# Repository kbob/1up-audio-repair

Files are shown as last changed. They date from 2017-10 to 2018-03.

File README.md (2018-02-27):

# Repair a 1UP's headphone jack.

This is a prototype of the
[1Bitsy-1UP](https://github.com/1Bitsy/1bitsy-1up)'s new audio output
section.  It is being implemented as a daughter card, but if it works,
it will be integrated into a future version of the 1Up

## Objectives

The new audio section will have these features.

 * Stereo headphone out or mono speaker out.

* Automatic switching between speaker and headphone when 'phones are
   plugged in.

* Thumbwheel for volume control.

* The volume wheel will directly control audio gain, but will also be
  readable by software.

* Headphone presence will directly control audio signal routing, but
  will also be readable by software. Software will produce stereo
  signal when the headphones are active and mono signal when the
  speaker is active.

* The amplifier's mute function will be controllable by software.

* The amplifier's shutdown (low power) function will be controllable
* by software.

## The Design

The audio output will be built around the PAM8019 amplifier from
Diodes Incorporated.  Headphone outputs will be routed to a 3.5mm
headphone jack.  Speaker outputs will be routed to a terminal block
for an off-board speaker.

The board will be configurable to take power either from the 1Bitsy's
+3v3 rail or from a separate power connection.

## Considerations

This is speculation based on the PAM8019 datasheet.

The 8019's digital input pins, MUTE and ~SD, are 3V compatible.  When
the 8019 is at 5V, a 3.3V GPIO will control those inputs.

The HP/~SPK input is not 3V compatible when the 8019 is at 5V.  The
HP/~SPK input will be generated directly from the headphone tip
switch.  In 5V operation, the 3V GPIO signal will be generated from a
voltage divider.  In 3V operation, the GPIO signal can be connected
directly to the tip switch.  (The GPIO pin happens to be an analog
input, so we could also leave the voltage divider in and read an
analog value instead of digital.)

The 8019's Volume input needs to have a range of 0 to +5V to give the
maximum attenuation of -60dB.  But the STM32's analog input can't
exceed 3.3v.  So a voltage divider is called for.  The problem is that
the Volume voltage already comes from a 50K potentiometer, which is a
voltage divider.  Adding another will make the volume control
nonlinear.

The 8019 has a circuit to detect low power and fade out the audio when
it happens.  It is supposed to suppress pops on power down.  It will
require experimentation to find the best resistor values for that.

The 8019 has a "non clip power limit" circuit.  The voltage at the PL
pin determines the maximum power the amp will deliver.  I will put in
a header to attach an external potentiometer to test various values of
PL with whatever speakers we decide to use.

## Interface

The board will connect directly to the 1Bitsy at the following
pins.  The pin arrangement will match the 1Bitsy's arrangement
so the boards can be stacked.

* +3V3
* GND
* PA0 for headphone tip sense
* PA1 for volume sense
* PA2 for Mute control
* PA3 for ~Shutdown control
* PA4/DAC1
* PA5/DAC2

A solder jumper will connect the amplifier VDD to the 1Bitsy's 3v3
supply.

There will be headers to attach external potentiometers or resistor
networks to dial in the correct values for the UVP and PL pins.

## Misc.

Here is a Maxim app note describing a headphone sense circuit.  Thanks
to James Hagerman for finding it and to an anonymous Maxim engineer
for writing it.

https://www.maximintegrated.com/en/app-notes/index.mvp/id/4607

## Errata

v0.2 holes are too small for the headphone jack.

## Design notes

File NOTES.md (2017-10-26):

# Notes

## 2017-10-26 which amp?

During IRC discussion, @esden, @scanlime, @jboone and myself (@kbob)
decided some things.

 * I²S is the right answer.  @jboone especially likes the AK4951.
   But the 1Bitsy does not have I²S pins available, and enabling it
   requires major rework.

 * The desired audio configuration is stereo headphones or mono
   speaker.  There is no desire to use them simultaneously.

 * The digital potentiometer is not needed.  Software volume control
   should be just fine.

Then we discussed a bunch of amplifier chips.  We did not reach a
decision.

 * TPA6135A2 (current chip) for headphones + TPA2012D2 for speaker

   Pros of TPA2012D2:
    + outputs are direct coupled

   Cons:
    - is stereo; we only need mono.

 * TPA0213 for both.  This actually meets our needs pretty well.
   It has three input channels, uses headphone presence detect
   to switch the speakers on and off.

   Cons:
    - power limited: 0.6W into 4Ω w/ 3V power.
    - outputs are capacitively coupled.

 * TPA601A4 for both.  @scanlime found this chip.  It is a stereo
   headphone/speaker amp with independent volume adjustments.

   Pros:
    + has a nice auto-fade function when switching between headphones
      and speakers.

   Cons:
    - speakers are stereo.
    - minimum recommended power voltage is 4V.
    - outputs are capacitively coupled.

 * PAM8019 for both.  Another @scanlime find.

   Pros:
    + Class AB for headphones, class D for speakers.
    + about 50¢ in quantity 100.

   Cons:
    - speakers are stereo.
    - headphone outputs are capacitively coupled.  (Speakers are direct.)

 * WM9094 for both.  Also @scanlime's.

   Pros:
    + tiny BGA package.

   Cons:
    - not readily available.
    - tiny BGA package.

 * @jboone mentioned that the Paper Jamz Pro used an amp from Nuvoton.
   No specific part was recommended.

Based on all this, I am leaning toward the PAM8019.  The TPA6135A2 +
TPA2012D2 are also okay.

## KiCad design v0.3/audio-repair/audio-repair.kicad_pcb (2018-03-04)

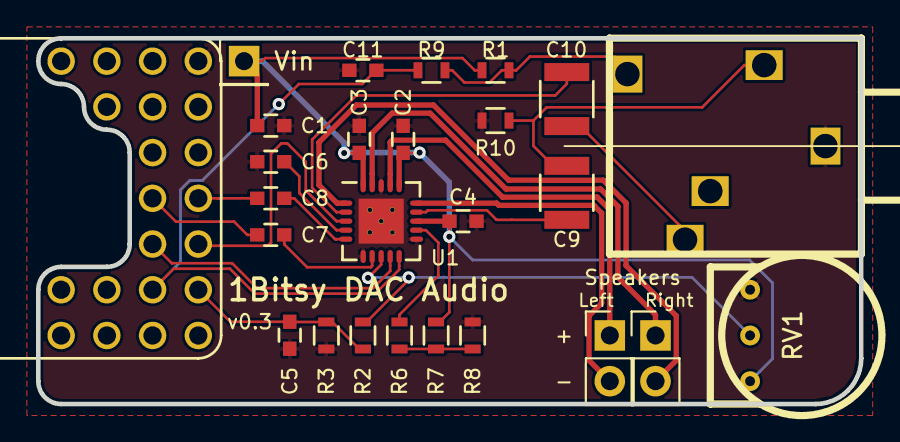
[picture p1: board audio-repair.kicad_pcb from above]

Board: 2 copper layers, 45.7 x 20.3 mm, 26 parts (0 on the bottom side), 23 nets.

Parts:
C1: 10µF; C_0603
C2, C3, C4, C11: 100nF; C_0603
C5: 10nF; C_0603
C6: 1µF; C_0603
C7, C8: 220nF; C_0603
C9, C10: 220µF; C_1210
J1: Vin; Pin_Header_Straight_1x01_Pitch2.54mm
J2: Switchcraft_35RAPC4BHN3
J4: Left; Pin_Header_Straight_1x02_Pitch2.54mm
J6: Right; Pin_Header_Straight_1x02_Pitch2.54mm
R1: 100K; R_0603
R2: 680K; R_0603
R3: 1M; R_0603
R6, R8: 33K; R_0603
R7: 18K; R_0603
R9: 51K; R_0603
R10: 10K; R_0603
RV1: 50K; Potentiometer_Bourns_3352T
U1: PAM8019KGR; QFN-20-1EP_4x4mm_Pitch0.5mm
U2: 1bitsy-basic-stubby; 1bitsy-stub

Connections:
/DAC_L: C7.2, U2.35
/DAC_R: C8.2, U2.36
/MUTE: U1.9, U2.33
/TIP_SW: C11.1, R9.2, U1.10, U2.31
/VOL_ADC: C5.1, R2.2, R3.1, U2.32
/~SHUTDOWN: U1.3, U2.34
GND: C1.2, C2.2, C3.2, C4.2, C5.2, C6.2, C11.2, J2.1, R3.2, R8.2, R10.1, RV1.1, U1.6, U1.11, U1.18, U1.21, U2.16
unnamed: C6.1, U1.4
unnamed: C7.1, U1.7
unnamed: C8.1, U1.5
unnamed: C9.1, U1.14
unnamed: C9.2, J2.5, R10.2
unnamed: C10.1, U1.2
unnamed: C10.2, J2.2
unnamed: J2.4, R1.2, R9.1
unnamed: J4.1, U1.17
unnamed: J4.2, U1.15
unnamed: J6.1, U1.19
unnamed: J6.2, U1.1
unnamed: R2.1, RV1.2, U1.8
unnamed: R6.1, R7.2, R8.1
unnamed: R6.2, U1.12
VDD: C1.1, C2.1, C3.1, C4.1, J1.1, R1.1, R7.1, RV1.3, U1.13, U1.16, U1.20

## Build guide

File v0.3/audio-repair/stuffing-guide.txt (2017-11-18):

Audio Repair v0.2
Stuffing Guide

U1  PAM8019KGR

C1   10µF
C2  100nF
C3  100nF
C4  100nF
C5  100nF
C6    1uF
C7  220nF
C8  220nF
C9  220µF
C10 220µF

R1  100K
R2  680K
R3    1M
R4   -
R5   -
R6  100K
R7   -
R8   -

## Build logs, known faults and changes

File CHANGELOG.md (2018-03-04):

# V0.3

## Schematic Changes

* J1 only has power, not ground. (This will still be a flying jumper to the
  1Bitsy’s VIN pin.)

* PL pin is tied low instead of having a voltage divider and header.

* UVP pin is tied to a voltage divider with resistor values specified and
  no header.

* HP/~SPK now has the MAXIM app note circuit to pull the pin low when
  'phones are disconnected and isolate the pin from the headphone jack.

* Speaker headers changed from screw terminals to 2.54mm headers.

* Board no longer has option to use 1Bitsy's 3v3 power.

## Board Changes

* Smaller form factor.

* Speaker jacks replaced with solder points.

* Lots of test/patch points removed.

* Mounting holes removed.

* Headphone jack holes enlarged.

# V0.2

## Schematic Changes

* add jumpers to voltage dividers on PL and UVP pin for experimentation.

* Make power supply jumper selectable (either +3V3 or external power).

## Board Changes

* Change board format to 2 inch square.  Make room to work instead of making
  it fit the 1Bitsy.

* Add through hole + SMD pads to most passives for easy change-out.

# V0.1

First version.

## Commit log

2017-10-22 Describe what this board should be and do.
2017-10-24 Add board schematic.
    [audio-repair.kicad_pcb, audio-repair.sch]
2017-10-24 Check in latecomers.
    [audio-repair.sch]
2017-10-27 Start over with a completely different audio design.
    [audio-repair.kicad_pcb, audio-repair.sch]
2017-10-27 Draw most of the schematic.
    [audio-repair.kicad_pcb, audio-repair.sch]
2017-10-28 Design headphone/speaker switch control.
    [audio-repair.sch]
2017-10-30 Create footprints, rough-place components on board.
    [audio-repair.kicad_pcb, audio-repair.sch]
2017-10-30 Align 1bitsy pins to 0.1" grid.
    [audio-repair.kicad_pcb]
2017-10-30 Align through-hole components to 0.1" grid.
    [audio-repair.kicad_pcb]
2017-10-30 Route all traces except ground pours.
    [audio-repair.kicad_pcb, audio-repair.sch]
2017-10-31 Pour grounds, clean up silkscreen.
    [audio-repair.kicad_pcb]
2017-10-31 Re-genericize the labels on library footprints.
2017-10-31 Moved all files to a v0.1 folder.
    [audio-repair.kicad_pcb, audio-repair.sch]
2017-10-31 Change pads in QFN footprint per @esden's suggestions.
2017-11-01 Layout v0.2 board (50x50mm).
    [audio-repair.kicad_pcb, audio-repair.sch]
2017-11-01 Add mounting holes; tweak stuff.
    [audio-repair.kicad_pcb]
2017-11-01 Change 3.3v jumper from solder jumper to pin header.
    [audio-repair.kicad_pcb, audio-repair.sch]
2017-11-01 Change Gerbil plot settings.
    [audio-repair.kicad_pcb]
2017-11-18 Create board stuffing guide.
2018-03-02 start v0.3 board revision.
    [audio-repair.kicad_pcb, audio-repair.sch]
2018-03-03 Create v0.3 schematic with lessons learned from v0.2.
    [audio-repair.sch]
2018-03-04 lay out v0.3 board.
    [audio-repair.kicad_pcb, audio-repair.sch]
